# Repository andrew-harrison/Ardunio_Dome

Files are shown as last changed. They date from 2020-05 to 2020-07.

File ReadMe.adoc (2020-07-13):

:Author: Andrew Harrison
:Email: harrison_andrew@outlook.com
:Date: 22/04/2020
:Revision: 01
:License: Public Domain

= Project: Plant Dome 🌵

Control system and data gathering of hardware used in plant dome. The components required include:

x4 LEDs at different frequencies used by the plant for photosynthesis (I used x4 MOSFETs with resistors to switch)
5V DC pump (I used a BJT and 5V relay to switch)
Capacitive soil moisture sensor
Ethernet shield to upload telemetry to google sheets (if required)

== Step 1: Installation

This project is developed in Visual studio code using the Platform IO platform (https://platformio.org/install/ide?install=vscode)

However any platform can be used to compile and flash code to the arduino. 

The following libraries must be installed to compile:

* Arduino.h
* Ethernet.h
* SPI.h

== Step 2: Assemble the circuit

Assemble the circuit following the diagram Dome_Schematic.png (alternatively this can be opened in the Fritzing file Dome_Schematic.fzz if modifications need to be made)

== Step 3: Load the code

Upload the code contained in this sketch on to your board

=== License
This project is released under a Public License.

=== BOM
Add the bill of the materials you need for this project.

|===
| ID | Part name           | Quantity
| P1 | 5V 2A pwr suppl     | 1
| A1 | Arduuno Mega        | 1
| E1 | Etherne shield      | 1
| B1 | Buck converter      | 1
| C1 | Moisture sensor     | 1
|LED#|3W LEDs              | 4
|Q1-4|N-type MOSFET 2A     | 4
|R1-4|1.2 ohm 1w resistor  | 4
|R5-8|47 kohm 1/4w resistor| 4
| M1 |5V pump              | 1
| Q5 | BJT transistor      | 1
| R9 | 330 ohm resistor    | 1
| S1 | 5V relay            | 1

|===

=== Help
Feel free to contact me on at: harrison_andrew@outlook.com

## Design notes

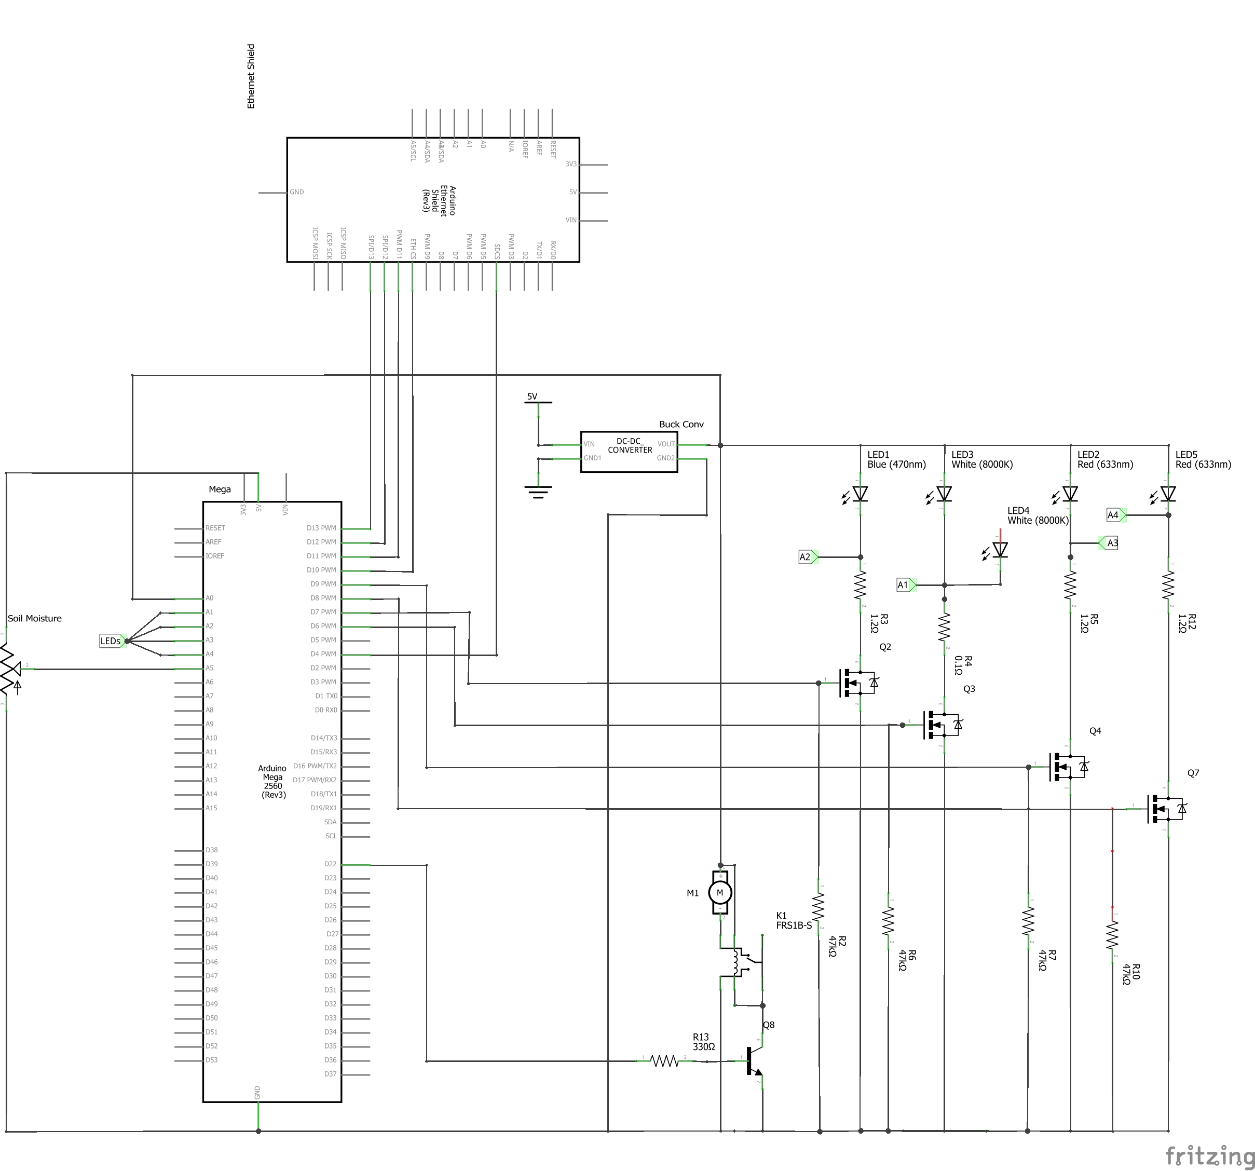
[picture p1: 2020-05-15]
Dome_Schematic.png

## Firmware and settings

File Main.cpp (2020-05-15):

#include "DOME.h"

byte brightness[4] = {0}; //Brightness of WHITE BLUE RED1 RED2 LEDs as PWM value


bool motor_trig = false;
byte soil_trigger = 70; // % Soil moisture level that triggers pump

unsigned long last_trigger;

bool network = false; // Debugging


//  Ethernet Settings
byte ip[] = {192, 168, 0, 0};
byte mac[] = { 0x90, 0xA2, 0xDA, 0x0D, 0x85, 0xD9 };
byte subnet[] = { 255, 255, 255, 0 }; //assigning subnet mask
byte gateway[] = { 192, 168, 1, 254 }; //assigning gateway
EthernetServer server(80);                       //server port


void setup() {

  Serial.begin(9600);
  Serial.println("Starting-up");
  pinMode(10, OUTPUT);
  digitalWrite(10, HIGH);
  pinMode(4, OUTPUT);
  digitalWrite(4, HIGH);
  
  pinMode(LED, OUTPUT);
  
  pinMode(WHITE, OUTPUT);
  pinMode(BLUE, OUTPUT);
  pinMode(RED1, OUTPUT);
  pinMode(RED2, OUTPUT);

  pinMode(REF_in, INPUT);
  pinMode(WHITE_in, INPUT);
  pinMode(BLUE_in, INPUT);
  pinMode(RED1_in, INPUT);
  pinMode(RED2_in, INPUT);

  pinMode(MOTOR, OUTPUT);

  pinMode(SOIL, INPUT);
  pinMode(WATER_LEVEL, INPUT);
 
 if(network){
  //Ethernet.begin(mac, ip, subnet, gateway);
  if (Ethernet.begin(mac) == 0) {
    Serial.println("Failed to configure Ethernet using DHCP");
    network = false;
    // for(;;); //do nothing forevermore:
  }  

  //Start the Ethernet connection:   
  Ethernet.begin(mac); //
  server.begin(); // start to listen for clients
  Serial.print("Server is at: ");
  Serial.println(Ethernet.localIP());

  Serial.println("Setting up DDNS");
  EasyDDNS.client("domeproject.webredirect.org","drew530","ARDUINOupdate");    // Enter ddns Hostname - Username - Client-key
  Serial.println("DDNS Set up");
  }
}

void loop() {
  // Updates the Routers IP public IP address every 10 minutes
  if(network){
  EasyDDNS.update(600000);
  Update_Webpage(server);
  }

  unsigned long time = millis(); 

  bool water = false;

  int light_vals[5]; // Supply voltage for lights as well as voltage from across W,B,R1 & R2 LEDs
  int v_ref[4] = {0};
  int power_level = 0; // 0 - 0x3FF LED voltage

  if (GetPowerLevel() != power_level){
    power_level = GetPowerLevel();
    float power_scale = (float)power_level/0x3FF;
    //Voltage reference for WHITE BLUE RED1 RED2 LEDs, where 1023 is 5v
    v_ref[0] = (int)(W_MIN+power_scale*(W_MAX-W_MIN));
    v_ref[1] = (int)(B_MIN+power_scale*(B_MAX-B_MIN));
    v_ref[2] = (int)(R_MIN+power_scale*(R_MAX-R_MIN));
    v_ref[3] = (int)(R_MIN+power_scale*(R_MAX-R_MIN));
    
    for(int i = 0; i<4; i++){
      Serial.print(v_ref[i]);
      Serial.print(" \t");
      Serial.print(brightness[i]);
      Serial.print(" \t");
    }
    Serial.println();
  };
  
  ReadLights(light_vals); // Pointer to first array element sent
  BrightnessController(light_vals, v_ref, brightness);
  SetLights(brightness);
  //GlowLights(brightness);

  //water = Soil_Measure(soil_trigger);
  if(water == true)
  {
    water = !water;
    digitalWrite(MOTOR, HIGH);
    Serial.println("Motor switch");
  };

    // Record data to GSheet every 5 sec
  if (time-last_trigger> 5000){
    last_trigger = time;
    SensData data;
    data.temp[0] = 1;

    for(int i=0; i<4; i++){
      data.LED_Ref_Voltages[i] = v_ref[i];
      Serial.print(data.LED_Ref_Voltages[i]);
      Serial.print("\t");
    };

    Serial.println();
    delay(500);
    
    if(network){
      SendToGDrive(data);
    }
    
    Serial.print("Above data sent to Drive");
   }


}

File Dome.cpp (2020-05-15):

#include <Arduino.h>
#include <Ethernet.h>

#include "DOME.h"

//Ethernet Functions
void SendToGDrive(SensData data){
  char serverName[] = "api.pushingbox.com";
  char devID[] = "vE07EE5D5E30E8D7"; // Unique ID for PushingBox
  unsigned long startTime = millis();
  Serial.println("Connecting to PushingBox...");
  
  EthernetClient pushing_client;
  
  if(pushing_client.connect(serverName, 80)){
    Serial.println("Connected to PushingBox!");

//    pushing_client.print("api.pushingbox.com/pushingbox?devid=vE07EE5D5E30E8D7&tempData=19");
    pushing_client.print("GET /pushingbox?devid=");
    pushing_client.print(devID);
    pushing_client.print("&tempData=");
    pushing_client.print(data.temp[0]);
    pushing_client.println(" HTTP/1.1");
    pushing_client.print("Host: ");
    pushing_client.println(serverName);
    pushing_client.println("User-Agent: Arduino Mega");
    pushing_client.println();
    delay(1);
    //pushing_client.stop();
  }
  
  Serial.print("Response from PushingBox: ");
  while(pushing_client.available()){
        char c = pushing_client.read();
        Serial.print(c);
    if((millis()-startTime)>1000){
        Serial.print("Pushing Box Timeout");
        break;
     }
  }
  
}

void Update_Webpage(EthernetServer server){
  // Update the ethernet client with
  EthernetClient client = server.available();
  
  // Update local webpage with sensor values and read any output requests
  if (client.available())
  { 
    Server_Requests(client);  
    HTML_page(client);
    Update_Sensor_Info(client);
  }

  client.stop();
}

void Server_Requests(EthernetClient client){
  String readString;

  char c = client.read();
  while (c != '\n' && client.available()){
  c = client.read();
  readString += c;
  Serial.write(c);
  delay(1);
  }

  Change_Light_State(readString);          
  readString=""; //clearing request
}

void HTML_page(EthernetClient client){

  // send a standard http response header
  client.println("HTTP/1.1 200 OK");
  client.println("Content-Type: text/html");
  // client.println("Connnection: close");
  client.println();

  client.println("<!DOCTYPE html>"); //web page is made using HTML
  client.println("<html>");
  client.println("<meta http-equiv=\"refresh\" content=\"2\">");
  client.println("<head>");
  client.println("<title>Ethernet Tests</title>");
  client.println("</head>");
  client.println("<hr /> <br />");
  client.println("<center>");
  client.println("<body>");
  client.println("<h1>First Attempts to read/write to Arduino </h1>");
  client.println("<h2>Observing State Of Dial</h2>");
  client.print("<h2>Dial is:  </2>");

  client.println("<a href=\"/?lighton\"\">Turn On Light</a>");
  client.println("<br /> <br />");
  client.println("<a href=\"/?lightoff\"\">Turn Off Light</a><br />");     

  client.println("</body>");
  client.println("</html>");
  
}

void Change_Light_State(String readString){
  if(readString.indexOf("?lighton") >0)//checks for on
  {
    digitalWrite(LED, HIGH);    // set pin 8 high
  }
  if(readString.indexOf("?lightoff") >0)//checks for off
    {
      digitalWrite(LED, LOW);    // set pin 8 low
    }
}

void Update_Sensor_Info(EthernetClient client){
  int sensorReading = analogRead(0);
  static int sensorSmooth;

  sensorSmooth = (99*sensorSmooth + sensorReading)/100;
  client.println("<br />");
  client.print("analog input ");
  client.print(0);
  client.print(" is ");
  client.print(sensorSmooth);
  client.print("<br />");
}

// Light Functions
int GetPowerLevel(){
  int level = analogRead(A9);
  return level;
}

void SetLights(byte *brightness){

    analogWrite(WHITE, brightness[0]);
    analogWrite(BLUE, brightness[1]);
    analogWrite(RED1, brightness[2]);
    analogWrite(RED2, brightness[3]);
}

void ReadLights(int *light_volt){
    
    int ref = analogRead(REF_in);
    *light_volt = ref; // Same as light_volt[0]
    light_volt[1] = ref - analogRead(WHITE_in);
    light_volt[2] = ref - analogRead(BLUE_in);
    light_volt[3] = ref - analogRead(RED1_in);
    light_volt[4] = ref - analogRead(RED2_in);

    // Serial.print(light_volt[0]*V_CONV);
    // Serial.print("\t");
    // Serial.print(light_volt[1]*V_CONV);
    // Serial.print("\t");
    // Serial.print(light_volt[2]*V_CONV);
    // Serial.print("\t");
    // Serial.print(light_volt[3]*V_CONV);
    // Serial.print("\t");
    // Serial.println(light_volt[4]*V_CONV);
}

void BrightnessController(int*v_now, int*v_ref, byte*brightness){
  const byte gain = 1;
  static float f_brightness[4];
  for (int i = 0; i < 4; i++)
  {
    signed int err = v_ref[i] - v_now[i+1]; //+1 because index 0 is + voltage rail
    f_brightness[i] = 0.99*f_brightness[i] + 0.01*(err*gain);
    // Serial.print(f_brightness[i]);
    // Serial.print(" ");

    if ( f_brightness[i]>= 255){
      brightness[i] = 255;
    }
    else if (f_brightness[i]<= 0){
      brightness[i] = 0;
    }    
    else{
      brightness[i] = (byte)f_brightness[i];
    }

    // Serial.print(brightness[i]);
    // Serial.print(" ");
    // Serial.print(err);
    // Serial.print("\t");
    // Serial.print(v_now[i+1]);
    // Serial.print("\t");
  }
  Serial.println("\t");
  delay(20);
}

void GlowLights(byte brightness[4])
{
    delay(25);

    for (byte i = 0; i <= 4; i++)
    {
        if(brightness[i]>=255){
            brightness[i] = 0;
        }
        else
        {
            brightness[i]++;
        }      
    }  
}


/*bool Soil_Trigger(byte trig){
    if (analogRead(SOIL)<trig){ // Value between 0 and 0x3FF, saturates at 2A7

        Serial.print("Soil sensor triggered at: ");
        Serial.print(analogRead(SOIL)/(679.0));
        Serial.println(" %");
        
        return true;
    }
    else
    {
        return false;
    };
     
}
*/

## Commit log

2020-05-03 Initial commit to change from Arduino IDE of platformio IDE
2020-05-06 Added schematic
    [Dome_Schematic.fzz]
2020-05-12 Updated schematic
    [Dome_Schematic.fzz]
2020-05-12 Removed old arduino .ino file
2020-05-14 changed chematic to include relay and transistor for pump
    [Dome_Schematic.fzz]
2020-05-15 Added analogue In to schematic
    [Dome_Schematic.fzz]
